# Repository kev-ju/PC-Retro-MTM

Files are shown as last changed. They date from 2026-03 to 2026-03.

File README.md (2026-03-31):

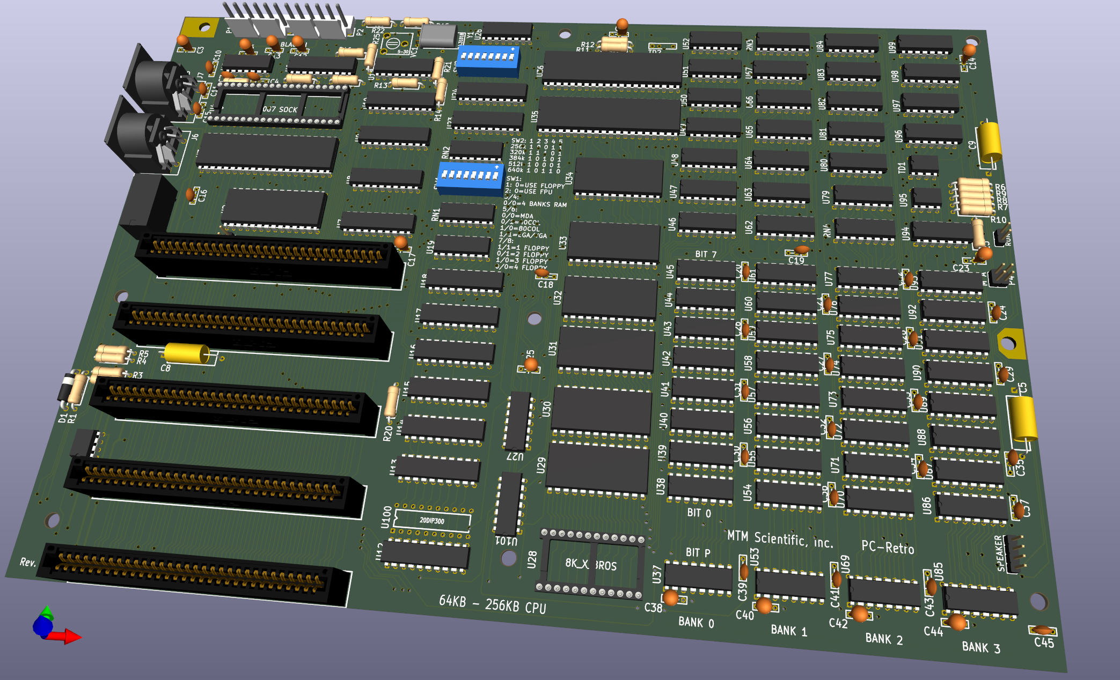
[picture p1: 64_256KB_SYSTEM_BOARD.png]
PC-Retro-MTM
 

# PC-Retro-MTM
Modern KiCad version of the IBM 5150 system board clone originally created by MTM Scientific, Inc.

Buy the original board (not from these files, not affiliated) [here](http://www.mtmscientific.com/pc-retro.html)

VCF [discussion](https://forum.vcfed.org/index.php?threads/pc-retro-design-files-ibm-5150-clone.1247940/)

## Notes
mmruzek @ VCF was very kind to open-source the design files of his IBM 5150 system board clone. The project used a version of KiCad from 2012 or so, and was not immediately usable in later KiCad versions. I converted it to KiCad 9 and did enough clean-up and repair to get forward and backward annotation working without issue, along with some small edits listed below. I have not fabricated these files. Use at your own risk. 

## Changes
- Fixed skewed edge cuts outline
- Silkscreen formatting to more closely match the style of the original IBM board, along with some assembly and operation hints
- Re-annotated the capacitors so that they have unique references
- Capacitor footprints to help assembly and improve component flexibility/availability
- Removed dangling traces and vias
- Added missing decoupling capacitor around RAM
- Changed keyboard power decoupling capacitor value
- Added keyboard clock line capacitor
- Added jumper for RESERVED ISA bus connection
- Updated 3D models

## BOM
I added a BOM into the KiCad schematic featuring only US-based retailers where possible. I have not verified these parts, use at your own risk. It may be cheaper to buy the TTL parts direct from [ti.com](https://ti.com). Do not buy the TTL parts from China, most will be relabeled HC. The RAM and 82XX parts have numerous equivalents, sometimes with quite different part numbers. 

If TD1 had its original DIP-14 footprint restored, the [DS1000-125](https://www.questcomp.com/part/4/ds1000-125/177327912) could be used.

EPROMS that work with the 5150 are not common. An adapter can be used as described at [MZD](https://www.minuszerodegrees.net/5150/motherboard/IBM%205150%20motherboard%20-%20Substituting%20the%20U33%20BIOS%20ROM.htm), or U28 could possibly be changed to a 27C512 or equivalent by using A13-A15 from the ISA slots and connecting ROM_ADDR_SEL to CE and XMEMR to OE.

IC Socket list:

3 x [DIP-8](https://www.digikey.com/en/products/detail/adam-tech/ICS-308-T/9829299)

19 x [DIP-14](https://www.digikey.com/en/products/detail/adam-tech/ICS-314-T/9832866)

51 x [DIP-16](https://www.digikey.com/en/products/detail/adam-tech/ICS-316-T/9832862)

2 x [DIP-18](https://www.digikey.com/en/products/detail/adam-tech/ICS-318-T/9832865)

14 x [DIP-20](https://www.digikey.com/en/products/detail/adam-tech/ICS-320-T/9832868)

7 x [DIP-24W](https://www.digikey.com/en/products/detail/adam-tech/ICS-624-T/9832867)

1 x [DIP-28W](https://www.digikey.com/en/products/detail/adam-tech/ICS-628-T/9832869)

40 x [DIP-40](https://www.digikey.com/en/products/detail/adam-tech/ICS-640-T/9832863)

| # | Reference | Value | Qty | Link | Note |
|---|---|---|-----|---|---|
| 1 | C2, C3, C6, C12, C13, C14, C17, C23, C25, C38, C40, C42, C44 | 10u | 13 | https://www.digikey.com/en/products/detail/kyocera-avx/TAP106K025SRS/11202552 | |
| 2 | C4, C10, C16, C18, C19, C20, C21, C22, C24, C26, C27, C28, C29, C30, C31, C32, C33, C34, C35, C36, C37, C39, C41, C43, C45 | .047u | 25 | https://www.digikey.com/en/products/detail/vishay-beyschlag-draloric-bc-components/K104K10X7RF5UH5/2356754 | No reason not to use 100n here |
| 3 | C5, C9 | .01u | 2 | https://www.digikey.com/en/products/detail/vishay-beyschlag-draloric-bc-components/MKT1813310405/5378151 | |
| 4 | C7, C11, C15 | 47p | 3 | https://www.digikey.com/en/products/detail/vishay-beyschlag-draloric-bc-components/K470J15C0GF5TH5/286492 | |
| 5 | C8 | .047u | 1 | https://www.digikey.com/en/products/detail/cornell-dubilier-knowles/150473K250BB/2538235 | |
| 6 | D1 | TYPE FC | 1 | https://www.digikey.com/en/products/detail/onsemi/1N4148/458603 | |
| 7 | J1, J2, J3, J4, J5 | I/O_CONNECTOR | 5 | https://www.digikey.com/en/products/detail/edac-inc/395-062-520-350/210777 | |
| 8 | J6 | CASSETTE | 1 | https://www.digikey.com/en/products/detail/kycon-inc/KCDX-5S-N/10246509 | |
| 9 | J7 | KBD | 1 | https://www.digikey.com/en/products/detail/kycon-inc/KCDX-5S-N/10246509 | |
| 12 | K1 | DIP_RELAY | 1 | https://www.digikey.com/en/products/detail/omron-electronics-inc-emc-div/G5V-2-DC5/87819 | |
| 13 | P1, P2 | POWER_CON | 2 | https://www.digikey.com/en/products/detail/molex/0366420001/4143772 | It's black instead of white, but it's the right shape. |
| 14 | P3 | 1x4 | 1 | https://www.digikey.com/en/products/detail/adam-tech/PH1RB-04-UA/9830473 | |
| 15 | P4 | 2x2 | 1 | https://www.digikey.com/en/products/detail/adam-tech/PH2-04-UA/9830324 | |
| 16 | R1, R3, R4, R5 | 18K | 4 | https://www.digikey.com/en/products/detail/yageo/MFR-25FTE52-18K/9139828 | |
| 17 | R2 | 1MEG | 1 | https://www.digikey.com/en/products/detail/yageo/MFR-25FTE52-1M/9139874 | |
| 18 | R6 | 150 | 1 | https://www.digikey.com/en/products/detail/yageo/MFR-25FBF52-150R/12831 | |
| 19 | R7 | 1200 | 1 | https://www.digikey.com/en/products/detail/yageo/MFR-25FBF52-1K2/9138061 | |
| 20 | R8 | 4.7K | 1 | https://www.digikey.com/en/products/detail/yageo/MFR-25FTF52-4K7/9140940 | |
| 21 | R9 | 3.9K | 1 | https://www.digikey.com/en/products/detail/yageo/MFR-25FTE52-3K9/9140156 | |
| 22 | R10 | 33 1/2W | 1 | https://www.digikey.com/en/products/detail/yageo/MFR50SFTE52-33R/9151419 | 1/2 watt |
| 23 | R11 | 180 | 1 | https://www.digikey.com/en/products/detail/yageo/MFR-25FTE52-180R/9139823 | |
| 24 | R12 | 220 | 1 | https://www.digikey.com/en/products/detail/yageo/MFR-25FRF52-220R/9138942 | |
| 25 | R13, R14, R15, R16, R17, R18, R19, R20, R21 | 27 | 9 | https://www.digikey.com/en/products/detail/yageo/MFR-25FTE52-27R/9140004 | |
| 26 | R22, R25 | 510 | 2 | https://www.digikey.com/en/products/detail/yageo/MFR-25FBF52-510R/9138187 | |
| 27 | R23 | 30 OHM | 1 | https://www.digikey.com/en/products/detail/yageo/MFR-25FTE52-30R/9140087 | |
| 28 | RN1, RN3 | 4.7k | 2 | https://www.digikey.com/en/products/detail/bourns-inc/4116R-2-472LF/1088687 | |
| 29 | RN2 | 8.2K | 1 | https://www.digikey.com/en/products/detail/bourns-inc/4116R-2-472LF/1088687 | There is no reason to use 8.2k here, another 4.7k will work fine. |
| 30 | RN4 | 30 OHM | 1 | https://www.digikey.com/en/products/detail/bourns-inc/4116R-1-330LF/1088635 | 33 Ohm will work fine here |
| 31 | SW1, SW2 | DIP_SW8 | 2 | https://www.digikey.com/en/products/detail/te-connectivity-alcoswitch-switches/435640-5/42470 | |
| 32 | TD1 | 125n | 1 | https://www.questcomp.com/part/4/ds1000m-125/177328069 | https://www.questcomp.com/part/4/ds1000m-100/177328066 probably also works |
| 33 | TD2 | 7ns | 1 | https://www.digikey.com/en/products/detail/yageo/MFR-25FTE52-470R/9140223 | Use a 470 Ohm resistor here |
| 34 | U1 | MC1741 | 1 | https://www.digikey.com/en/products/detail/texas-instruments/LM741CN-NOPB/6322 | |
| 35 | U2 | 8259A | 1 | https://www.jameco.com/z/P8259A-Intel-Corporation-IC-8259-Programmable-Interrupt-Controller-DIP-28-pin_52775.html | |
| 36 | U3 | 8088 | 1 | https://www.jameco.com/z/P8088-2-Advanced-Micro-Devices-MPU-8088-CISC-8-Bit-HMOS-8MHz-40-Pin-CDIP_52169.html | |
| 37 | U4 | 8087 | 1 | https://www.questcomp.com/part/4/c8087/126791059 | |
| 38 | U5 | 74LS30 | 1 | https://www.digikey.com/en/products/detail/texas-instruments/SN74LS30N/377726 | |
| 39 | U6 | 8288 | 1 | https://www.questcomp.com/part/4/cp82c88/146639310 | |
| 40 | U7, U9, U10, U18 | 74LS373 | 4 | https://www.digikey.com/en/products/detail/texas-instruments/SN74LS373N/277306 | |
| 41 | U8, U12, U13, U14 | 74LS245 | 4 | https://www.digikey.com/en/products/detail/texas-instruments/SN74LS245N/277301 | |
| 42 | U11 | 8284A | 1 | https://www.questcomp.com/part/4/cp82c84a/146639293 | |
| 43 | U15, U16, U17, U23 | 74LS244 | 4 | https://www.digikey.com/en/products/detail/texas-instruments/SN74LS244N/277299 | |
| 44 | U19 | 74LS670 | 1 | https://www.digikey.com/en/products/detail/texas-instruments/SN74LS670N/1594880 | |
| 45 | U24 | 74LS322 | 1 | https://www.jameco.com/z/AM25LS22PC-Advanced-Micro-Devices-8-Bit-Serial-Parallel-Register-IC-with-Sign-Extend-DIP-20_2395479.html | *** Investigate replacing this |
| 46 | U26, U98 | 74LS175 | 2 | https://www.digikey.com/en/products/detail/texas-instruments/SN74LS175N/277294 | |
| 47 | U27, U50 | 74LS02 | 2 | https://www.digikey.com/en/products/detail/texas-instruments/SN74LS02N/277273 | |
| 48 | U28, U29, U30, U31, U32, U33 | 8K_X_8ROS | 6 | https://www.minuszerodegrees.net/5150/motherboard/IBM%205150%20motherboard%20-%20Substituting%20the%20U33%20BIOS%20ROM.htm | |
| 49 | U34 | 8253-5 | 1 | https://www.jameco.com/z/P8253-Intel-Corporation-Programmable-Interval-Timer-3-Independent-16-bit-Counters-2-6-MHz-DIP-24_52679.html | |
| 50 | U35 | 8237A | 1 | https://www.jameco.com/z/P8237A-5-NEC-Corporation-Multimode-DMA-Controller-4-Channel-5-MHz-DIP-40_2394975.html | |
| 51 | U36 | 8255A-5 | 1 | https://www.jameco.com/z/P8255A-5-Intel-Corporation-IC-8255A-5-Programmable-Peripheral-Interface-40-pin-DIP_52732.html | |
| 52 | U37, U38, U39, U40, U41, U42, U43, U44, U45, U53, U54, U55, U56, U57, U58, U59, U60, U61, U69, U70, U71, U72, U73, U74, U75, U76, U77, U85, U86, U87, U88, U89, U90, U91, U92 | RAM_64K_X_1 | 36 | https://www.jameco.com/z/KM4164B-12-Samsung-Electronics-IC-4164-120-NMOS-DRAM-64K-Bit-64K-x-1-120ns-w-Page-Mode_2290535.html | |
| 53 | U46, U47, U48, U66 | 74LS138 | 4 | https://www.digikey.com/en/products/detail/texas-instruments/SN74LS138N/277285 | |
| 54 | U49, U97 | 74S08 | 2 | https://www.digikey.com/en/products/detail/texas-instruments/SN74S08N/277371 | |
| 55 | U51, U83, U99 | 74LS04 | 3 | https://www.digikey.com/en/products/detail/texas-instruments/SN74LS04N/277275 | |
| 56 | U52 | 74LS00 | 1 | https://www.digikey.com/en/products/detail/texas-instruments/SN74LS00N/277272 | |
| 57 | U62, U79 | 74LS158 | 2 | https://www.digikey.com/en/products/detail/texas-instruments/SN74LS158N/1594759 | |
| 58 | U63 | 74LS38 | 1 | https://www.digikey.com/en/products/detail/texas-instruments/SN74LS38N/277310 | |
| 59 | U64 | 74LS20 | 1 | https://www.digikey.com/en/products/detail/texas-instruments/SN74LS20N/377790 | |
| 60 | U65 | 74S138 | 1 | https://www.digikey.com/en/products/detail/texas-instruments/SN74S138AN/277374 | |
| 61 | U67, U96 | 74LS74 | 2 | https://www.digikey.com/en/products/detail/texas-instruments/SN74LS74AN/277314 | |
| 62 | U80 | 74LS125 | 1 | https://www.digikey.com/en/products/detail/texas-instruments/SN74LS125AN/277284 | |
| 63 | U81 | 74S00 | 1 | https://www.digikey.com/en/products/detail/texas-instruments/SN74S00N/277369 | |
| 64 | U82 | 74S74 | 1 | https://www.digikey.com/en/products/detail/texas-instruments/SN74S74N/277380 | |
| 65 | U84 | 74S10 | 1 | https://www.mouser.com/ProductDetail/Texas-Instruments/SN74S10N?qs=dT9u2OTAaVW2XijXSK8i5w%3D%3D | |
| 66 | U94 | 74S280 | 1 | https://www.jameco.com/z/DM74S280N-National-Semiconductor-9-Bit-Parity-Generator-Checker-IC-DIP-14_48688.html | *** Investigate replacing this |
| 67 | U95 | 75477 | 1 | https://www.digikey.com/en/products/detail/texas-instruments/SN75477P/380178 | |
| 68 | U101 | 74LS32 | 1 | https://www.digikey.com/en/products/detail/texas-instruments/SN74LS32N/277304 | |
| 69 | VC1 | 5-30 | 1 | https://www.digikey.com/en/products/detail/ew-electronics/GKG30015/11689271 | Bend the leads a bit to fit across pins 1 and 2. |
| 70 | Y1 | 14.31818 | 1 | https://www.digikey.com/en/products/detail/cts-frequency-controls/MP143/67739 | |

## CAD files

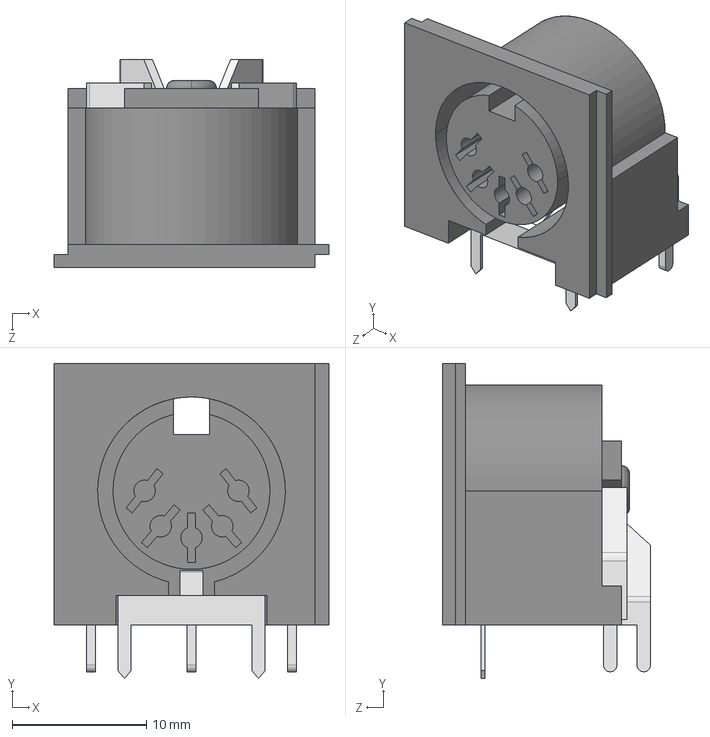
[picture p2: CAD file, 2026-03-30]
3D/KCDX-5S-N_rA3.IGS
20.5 x 23.5 x 15.5 mm

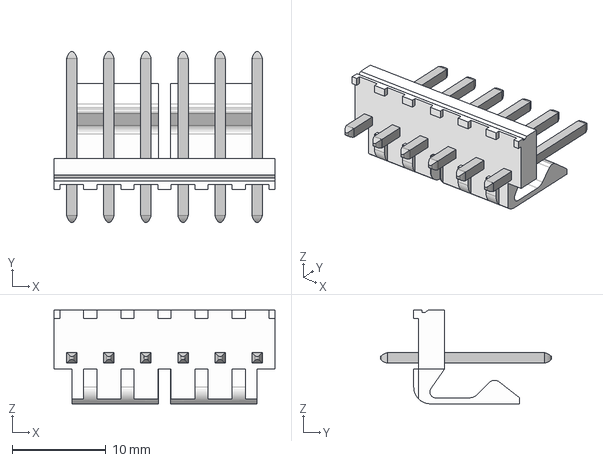
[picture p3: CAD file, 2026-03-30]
3D/26604060.stp
23.6 x 18.3 x 10.0 mm

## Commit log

2026-03-30 Fixed LS and S parts
    [64_256KB_SYSTEM_BOARD-B_Cu.gbr, 64_256KB_SYSTEM_BOARD-B_Mask.gbr, 64_256KB_SYSTEM_BOARD-Edge_Cuts.gbr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]
2026-03-31 3d view
    [64_256KB_SYSTEM_BOARD-B_Cu.gbr, 64_256KB_SYSTEM_BOARD-B_Mask.gbr, 64_256KB_SYSTEM_BOARD-Edge_Cuts.gbr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]
2026-03-31 added BOM
    [64_256KB_SYSTEM_BOARD.kicad_sch, SHEET1.kicad_sch, SHEET10.kicad_sch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]
2026-03-31 fixed td1 bom
    [SHEET3.kicad_sch]
